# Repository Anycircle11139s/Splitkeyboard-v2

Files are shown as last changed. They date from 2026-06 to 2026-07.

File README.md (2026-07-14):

# SPLIT-KEYBOARD-V2
The second attempt of creating the prefect split keyboard by @NotALarp
## WHAT IS IT?
This is my custom split keyboard made in KiCad, based on a LILY58 split keyboard design, it is sleek and is designed with ergonomics in mind. 

## Featured Hardware:
- Nice!Nano v2 microcontroller
- Lipo batteries
- Low profile choc switches
- 0.91" OLED displays
- EC11 Rotary Encoders

## WHY I MADE IT
My first split keyboard was pretty bad, it was based on a xiao nrf58240 microcontroller, had a terrible layout and overall wasn't that good. So I decided that with my previous knowledge that I would create a new, second split keyboard. 

## NOTES AND DESIGN CHOICES
This  time I decided to base the layout on a real split keyboard and some better microcontrollers. I decided on the nice!nano v2 and based the layout on a Lily58 split keyboard which I think looks really good. I designed a custom, 3d-printed case which was created to be compact, modern and sleek. 

## GALLERY
Screenshot 2026-06-01 at 7 38 29 pm
Screenshot 2026-06-04 at 8 28 54 pm
Screenshot 2026-06-09 at 4 20 33 pm
Screenshot 2026-06-09 at 7 04 58 pm
Screenshot 2026-06-10 at 5 05 12 pm

<br>

## BOM
<br>
https://docs.google.com/document/d/1G1sLWLXkf7hAwwnX9o8N8jDjILno_Bk2AuGZwasASP0/edit?usp=sharing

<br>

<br>

|Name |Purpose |Quantity|Total Cost (USD)|Link |Distributor |
|---|---|---|---|---|---|
|M3 screws |To screw everything into place |1 |3.00 |https://www.aliexpress.com/item/1005008810897680.html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 |Ali express |
|Keycaps |to cover the switches |1 |25.00 |https://www.aliexpress.com/item/1005006734545486.html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 |Ali express |
|Case shipping and printing |The 3D printed case |1 |0.00 | |Printing Legion|
|PCB |To hold/wire everything together |1 |26.00 | |JLCPCB |
|Rubber Feat |to keep the keyboard in place while typing |1 |3.00 |https://www.aliexpress.com/item/1005009513504427.html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 |Ali express |
|Lipo batteries |For making the thing have power while wireless  |2 |14.00 |https://www.aliexpress.com/item/32660019420.html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 |Ali express |
|JST pin connector |To connect Lipo batteries |1 |1.30 |https://www.aliexpress.com/item/1005004955655144.html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 |Ali express |
|Nice!Nano 2 drop in replacement|Microcontroller |2 |12.00 |https://www.aliexpress.com/item/1005012324856273.html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 |Ali express |
|Rotary encoder |The turning sensor for volume/brightness control|2 |4.00 |https://www.aliexpress.com/item/1005006693443387.html |Ali express |
|2M resistors |Battery sensing |1 |2.30 |https://www.aliexpress.com/item/1005006984056678.html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 |Ali express |
|806K resistors |Battery Sense |1 |2.30 |https://www.aliexpress.com/item/1005005184230104.html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 |Ali express |
|OLEDs |Displays |2 |5.00 |https://www.aliexpress.com/item/1005009252203585.html |Ali express |
|Diodes |For individual keys to click |1 |2.70 |https://www.aliexpress.com/item/1005007536719404.html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 |Ali express |
|Low Profile Choc Switches |Buttons for the keyboard |1 |20.00 |https://www.aliexpress.com/item/1005005883472162.html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|Ali Express |

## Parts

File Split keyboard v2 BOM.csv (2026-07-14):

Name | Purpose | Quantity | Total Cost (USD) | Link | Distributor
M3 screws | To screw everything into place | 1 | 3.00 | https://www.aliexpress.com/item/1005008810897680.html | Ali express
Keycaps | to cover the switches | 1 | 25.00 | https://www.aliexpress.com/item/1005006734545486.html | Ali express
Case shipping and printing | The 3D printed case | 1 | 0.00 |  | Printing Legion
PCB | To hold/wire everything together | 1 | 26.00 |  | JLCPCB
Rubber Feat | to keep the keyboard in place while typing | 1 | 3.00 | https://www.aliexpress.com/item/1005009513504427.html?curPageLogUid=5WTu2EJR6cb9 | Ali express
Lipo batteries | For making the thing have power while wireless | 2 | 14.00 | https://www.aliexpress.com/item/32660019420.html | Ali express
JST pin connector | To connect Lipo batteries | 1 | 1.30 | https://www.aliexpress.com/item/1005004955655144.html?curPageLogUid=SeM6XgBLqABt | Ali express
Nice!Nano 2 drop in replacement | Microcontroller | 2 | 12.00 | https://www.aliexpress.com/item/1005012324856273.html?curPageLogUid=t0nqsjWoAD10 | Ali express
Rotary encoder | The turning sensor for volume/brightness control | 2 | 4.00 | https://www.aliexpress.com/item/1005006693443387.html | Ali express
2M resistors | Battery sensing | 1 | 2.30 | https://www.aliexpress.com/item/1005006984056678.html?curPageLogUid=W9kpVUtpsgGF | Ali express
806K resistors | Battery Sense | 1 | 2.30 | https://www.aliexpress.com/item/1005005184230104.html?curPageLogUid=3ZB85ZmHR85W | Ali express
OLEDs | Displays | 2 | 5.00 | https://www.aliexpress.com/item/1005009252203585.html | Ali express
Diodes | For individual keys to click | 1 | 2.70 | https://www.aliexpress.com/item/1005007536719404.html?curPageLogUid=7tkJWryZP639 | Ali express
Low Profile Choc Switches | Buttons for the keyboard | 1 | 20.00 | https://www.aliexpress.com/item/1005005883472162.html?curPageLogUid=ecY0FsHMIH2l | Ali Express

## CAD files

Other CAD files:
Split keyboard v2 CAD/Final Assembly/Split keyboard v2 final assembly.step
Split keyboard v2 CAD/Bottom Left/Split keyboard v2 case part 1.step
Split keyboard v2 CAD/Bottom Right/Split keyboard v2 case part 3.step
Split keyboard v2 CAD/PCB CAD/Split keyboard pcb v2.step
Split keyboard v2 CAD/Top Left/Split keyboard v2 case part 2.step
Split keyboard v2 CAD/Top Right/Split keyboard v2 case part 4.step
Split keyboard v2 CAD/Bottom Left/Split keyboard v2 case part 1.f3d
Split keyboard v2 CAD/Bottom Left/Split keyboard v2 case part 1.stl
Split keyboard v2 CAD/Bottom Right/Split keyboard v2 case part 3.f3d
Split keyboard v2 CAD/Bottom Right/Split keyboard v2 case part 3.stl
Split keyboard v2 CAD/Final Assembly/Split keyboard v2 final assembly.f3d
Split keyboard v2 CAD/Final Assembly/Split keyboard v2 final assembly.stl
Split keyboard v2 CAD/PCB CAD/Split keyboard pcb v2.stl
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

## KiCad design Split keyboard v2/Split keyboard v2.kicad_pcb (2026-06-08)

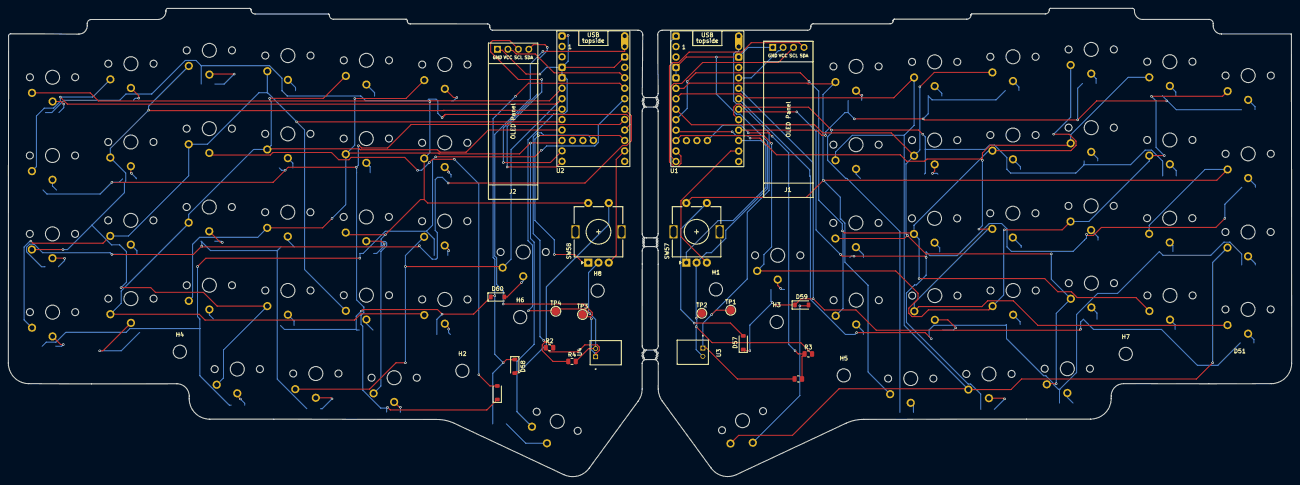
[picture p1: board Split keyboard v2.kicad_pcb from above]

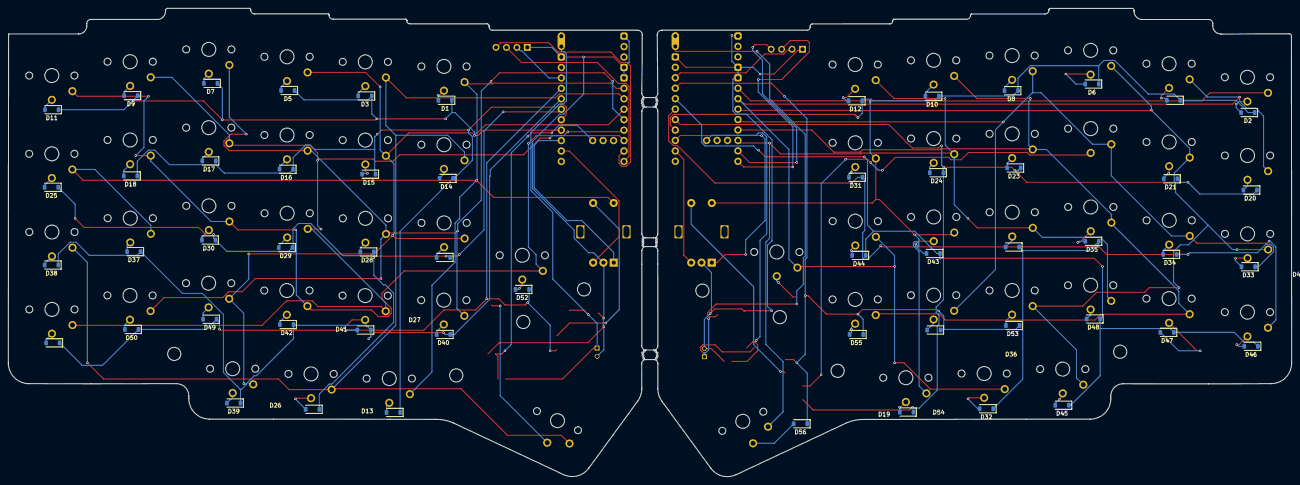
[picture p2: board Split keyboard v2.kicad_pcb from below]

Board: 2 copper layers, 312.1 x 113.9 mm, 142 parts (55 on the bottom side), 97 nets.

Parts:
CH1, CH2, CH3, CH4, CH5, CH6, CH7, CH8, CH9, CH10, CH11, CH12, CH13, CH14, CH15, CH16, CH17, CH18, CH19, CH20, CH21, CH22, CH23, CH24, CH25, CH26, CH27, CH28, CH29, CH30, CH31, CH32, CH33, CH34, CH35, CH36, CH37, CH38, CH39, CH40, CH41, CH42, CH43, CH44, CH45, CH46, CH47, CH48, CH49, CH50, CH51, CH52, CH53, CH54, CH55, CH56, CH57, CH58: choc_v1_SW_solder; SW_choc_v1_1u
D1, D2, D3, D4, D5, D6, D7, D8, D9, D10, D11, D12, D13, D14, D15, D16, D17, D18, D19, D20, D21, D22, D23, D24, D25, D26, D27, D28, D29, D30, D31, D32, D33, D34, D35, D36, D37, D38, D39, D40, D41, D42, D43, D44, D45, D46, D47, D48, D49, D50, D51, D52, D53, D54, D55, D56, D57, D58, D59, D60: D; D_SOD-123
H1, H2, H3, H4, H5, H6, H7, H8: MountingHole; MountingHole_3.2mm_M3
J1, J2: Conn_01x04_Socket; SSD1306-0.91-OLED-4pin-128x32
R1, R2: 806K; R_0805_2012Metric
R3, R4: 2M; R_0805_2012Metric
SW57, SW58: RotaryEncoder_Switch; RotaryEncoder_Alps_EC11E-Switch_Vertical_H20mm
TP1, TP3: BAT; TestPoint_Pad_D2.0mm
TP2, TP4: GND; TestPoint_Pad_D2.0mm
U1, U2: nice_nano; nice_nano_AH_USBup
U3, U4: S2B-PH-K-S(LF)(SN); JST_S2B-PH-K-S_LF__SN_

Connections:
/left/BT_PIN: R1.2, R3.1, U1.27 (P1.07-LF)
/left/COL0: CH1.1, CH13.1, CH25.1, CH37.1, SW57.S2, U1.5 (P0.17)
/left/COL1: CH3.1, CH15.1, CH27.1, CH39.1, CH57.1, U1.6 (P0.20)
/left/COL2: CH5.1, CH17.1, CH29.1, CH41.1, CH49.1, U1.7 (P0.22)
/left/COL3: CH7.1, CH19.1, CH31.1, CH43.1, CH51.1, U1.8 (P0.24)
/left/COL4: CH9.1, CH21.1, CH33.1, CH45.1, CH53.1, U1.9 (P1.00)
/left/COL5: CH11.1, CH23.1, CH35.1, CH47.1, CH55.1, U1.10 (P0.11)
/left/Encoder_A: SW57.A, U1.22 (P1.11-LF)
/left/Encoder_B: SW57.B, U1.23 (P0.10-LF)
/left/ROW0: D1.1 (K), D3.1 (K), D5.1 (K), D7.1 (K), D9.1 (K), D11.1 (K), U1.21 (P1.13-LF)
/left/ROW1: D13.1 (K), D14.1 (K), D15.1 (K), D16.1 (K), D17.1 (K), D18.1 (K), U1.20 (P1.15-LF)
/left/ROW2: D25.1 (K), D26.1 (K), D27.1 (K), D28.1 (K), D29.1 (K), D30.1 (K), U1.19 (P0.02-LF)
/left/ROW3: D37.1 (K), D38.1 (K), D39.1 (K), D40.1 (K), D41.1 (K), D42.1 (K), U1.18 (P0.29-LF)
/left/ROW4: D49.1 (K), D50.1 (K), D51.1 (K), D52.1 (K), D57.1 (K), D59.1 (K), U1.17 (P0.31-LF)
/left/SCL: J1.3, U1.12 (P1.06-LF)
/left/SDA: J1.4, U1.11 (P1.04-LF)
/left/VBAT: R1.1, TP1.1 (1_1), U1.13 (BAT+), U1.29 (BAT+), U3.1
/left/VCC: J1.2, U1.16 (3V3)
/right/BT_PIN: R2.2, R4.1, U2.27 (P1.07-LF)
/right/COL0: CH2.1, CH14.1, CH26.1, CH38.1, SW58.S2, U2.5 (P0.17)
/right/COL1: CH4.1, CH16.1, CH28.1, CH40.1, CH58.1, U2.6 (P0.20)
/right/COL2: CH6.1, CH18.1, CH30.1, CH42.1, CH50.1, U2.7 (P0.22)
/right/COL3: CH8.1, CH20.1, CH32.1, CH44.1, CH52.1, U2.8 (P0.24)
/right/COL4: CH10.1, CH22.1, CH34.1, CH46.1, CH54.1, U2.9 (P1.00)
/right/COL5: CH12.1, CH24.1, CH36.1, CH48.1, CH56.1, U2.10 (P0.11)
/right/Encoder_A: SW58.A, U2.22 (P1.11-LF)
/right/Encoder_B: SW58.B, U2.23 (P0.10-LF)
/right/ROW0: D2.1 (K), D4.1 (K), D6.1 (K), D8.1 (K), D10.1 (K), D12.1 (K), U2.21 (P1.13-LF)
/right/ROW1: D19.1 (K), D20.1 (K), D21.1 (K), D22.1 (K), D23.1 (K), D24.1 (K), U2.20 (P1.15-LF)
/right/ROW2: D31.1 (K), D32.1 (K), D33.1 (K), D34.1 (K), D35.1 (K), D36.1 (K), U2.19 (P0.02-LF)
/right/ROW3: D43.1 (K), D44.1 (K), D45.1 (K), D46.1 (K), D47.1 (K), D48.1 (K), U2.18 (P0.29-LF)
/right/ROW4: D53.1 (K), D54.1 (K), D55.1 (K), D56.1 (K), D58.1 (K), D60.1 (K), U2.17 (P0.31-LF)
/right/SCL: J2.3, U2.12 (P1.06-LF)
/right/SDA: J2.4, U2.11 (P1.04-LF)
/right/VBAT: R2.1, TP3.1 (1_1), U2.13 (BAT+), U2.29 (BAT+), U4.1
/right/VCC: J2.2, U2.16 (3V3)
GND: J1.1, J2.1, R3.2, R4.2, SW57.C, SW58.C, TP2.1 (1_1), TP4.1 (1_1), U1.3 (GND), U1.4 (GND), U1.14 (GND), U1.28 (GND), U2.3 (GND), U2.4 (GND), U2.14 (GND), U2.28 (GND), U3.2, U4.2
unnamed: CH1.2, D1.2 (A)
unnamed: CH2.2, D2.2 (A)
unnamed: CH3.2, D3.2 (A)
unnamed: CH4.2, D4.2 (A)
unnamed: CH5.2, D5.2 (A)
unnamed: CH6.2, D6.2 (A)
unnamed: CH7.2, D7.2 (A)
unnamed: CH8.2, D8.2 (A)
unnamed: CH9.2, D9.2 (A)
unnamed: CH10.2, D10.2 (A)
unnamed: CH11.2, D11.2 (A)
unnamed: CH12.2, D12.2 (A)
unnamed: CH13.2, D13.2 (A)
unnamed: CH15.2, D14.2 (A)
unnamed: CH17.2, D15.2 (A)
unnamed: CH19.2, D16.2 (A)
unnamed: CH21.2, D17.2 (A)
unnamed: CH23.2, D18.2 (A)
unnamed: CH14.2, D19.2 (A)
unnamed: CH16.2, D20.2 (A)
unnamed: CH18.2, D21.2 (A)
unnamed: CH20.2, D22.2 (A)
unnamed: CH22.2, D23.2 (A)
unnamed: CH24.2, D24.2 (A)
unnamed: CH25.2, D25.2 (A)
unnamed: CH27.2, D26.2 (A)
unnamed: CH29.2, D27.2 (A)
unnamed: CH31.2, D28.2 (A)
unnamed: CH33.2, D29.2 (A)
unnamed: CH35.2, D30.2 (A)
unnamed: CH26.2, D31.2 (A)
unnamed: CH28.2, D32.2 (A)
unnamed: CH30.2, D33.2 (A)
unnamed: CH32.2, D34.2 (A)
unnamed: CH34.2, D35.2 (A)
unnamed: CH36.2, D36.2 (A)
unnamed: CH37.2, D37.2 (A)
unnamed: CH39.2, D38.2 (A)
unnamed: CH41.2, D39.2 (A)
unnamed: CH43.2, D40.2 (A)
unnamed: CH45.2, D41.2 (A)
unnamed: CH47.2, D42.2 (A)
unnamed: CH38.2, D43.2 (A)
unnamed: CH40.2, D44.2 (A)
unnamed: CH42.2, D45.2 (A)
unnamed: CH44.2, D46.2 (A)
unnamed: CH46.2, D47.2 (A)
unnamed: CH48.2, D48.2 (A)
unnamed: CH49.2, D49.2 (A)
unnamed: CH51.2, D50.2 (A)
unnamed: CH53.2, D51.2 (A)
unnamed: CH55.2, D52.2 (A)
unnamed: CH50.2, D53.2 (A)
unnamed: CH52.2, D54.2 (A)
unnamed: CH54.2, D55.2 (A)
unnamed: CH56.2, D56.2 (A)
unnamed: D57.2 (A), SW57.S1
unnamed: D58.2 (A), SW58.S1
unnamed: CH57.2, D59.2 (A)
unnamed: CH58.2, D60.2 (A)

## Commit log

2026-06-11 Update README with CAD files link
    Added a link to Google Drive for CAD files.
2026-06-29 Add CAD folder to existing repo via LFS
    [Split keyboard pcb v2.step, Split keyboard pcb v2.stl, Split keyboard v2 case part 1.f3d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]
2026-07-14 Rename Split keyboard v2 CAD/Split keyboard v2 final assembly.f3d to Split keyboard v2 CAD/Final Assembly/Split keyboard v2 final assembly.f3d
    [Split keyboard v2 final assembly.f3d]
2026-07-14 Rename Split keyboard v2 CAD/Split keyboard v2 final assembly.stl to Split keyboard v2 CAD/Final Assembly/Split keyboard v2 final assembly.stl
    [Split keyboard v2 final assembly.stl]
2026-07-14 Rename Split keyboard v2 CAD/Split keyboard v2 final assembly.step to Split keyboard v2 CAD/Final Assembly/Split keyboard v2 final assembly.step
    [Split keyboard v2 final assembly.step]
2026-07-14 Rename Split keyboard v2 CAD/Split keyboard pcb v2.step to Split keyboard v2 CAD/PCB CAD/Split keyboard pcb v2.step
    [Split keyboard pcb v2.step]
2026-07-14 Rename Split keyboard v2 CAD/Split keyboard pcb v2.stl to Split keyboard v2 CAD/PCB CAD/Split keyboard pcb v2.stl
    [Split keyboard pcb v2.stl]
2026-07-14 Move Split keyboard v2 case part 1 to Bottom Left folder
    [Split keyboard v2 case part 1.stl]
2026-07-14 Rename Split keyboard v2 CAD/Split keyboard v2 case part 1.f3d to Split keyboard v2 CAD/Bottom Left/Split keyboard v2 case part 1.f3d
    [Split keyboard v2 case part 1.f3d]
2026-07-14 Rename Split keyboard v2 CAD/Split keyboard v2 case part 1.step to Split keyboard v2 CAD/Bottom Left/Split keyboard v2 case part 1.step
    [Split keyboard v2 case part 1.step]
2026-07-14 Rename Split keyboard v2 CAD/Split keyboard v2 case part 2.stl to Split keyboard v2 CAD/Top Left/Split keyboard v2 case part 2.stl
    [Split keyboard v2 case part 2.stl]
2026-07-14 Rename Split keyboard v2 CAD/Split keyboard v2 case part 2.f3d to Split keyboard v2 CAD/Top Left/Split keyboard v2 case part 2.f3d
    [Split keyboard v2 case part 2.f3d]
2026-07-14 Rename Split keyboard v2 CAD/Split keyboard v2 case part 2.step to Split keyboard v2 CAD/Top Left/Split keyboard v2 case part 2.step
    [Split keyboard v2 case part 2.step]
2026-07-14 Rename Split keyboard v2 CAD/Split keyboard v2 case part 3.stl to Split keyboard v2 CAD/Bottom Right/Split keyboard v2 case part 3.stl
    [Split keyboard v2 case part 3.stl]
2026-07-14 Rename Split keyboard v2 CAD/Split keyboard v2 case part 3.step to Split keyboard v2 CAD/Bottom Right/Split keyboard v2 case part 3.step
    [Split keyboard v2 case part 3.step]
2026-07-14 Rename Split keyboard v2 CAD/Split keyboard v2 case part 3.f3d to Split keyboard v2 CAD/Bottom Right/Split keyboard v2 case part 3.f3d
    [Split keyboard v2 case part 3.f3d]
2026-07-14 Rename Split keyboard v2 CAD/Split keyboard v2 case part 4.f3d to Split keyboard v2 CAD/Top Right/Split keyboard v2 case part 4.f3d
    [Split keyboard v2 case part 4.f3d]
2026-07-14 Rename Split keyboard v2 CAD/Split keyboard v2 case part 4.step to Split keyboard v2 CAD/Top Right/Split keyboard v2 case part 4.step
    [Split keyboard v2 case part 4.step]
2026-07-14 Rename Split keyboard v2 CAD/Split keyboard v2 case part 4.stl to Split keyboard v2 CAD/Top Right/Split keyboard v2 case part 4.stl
    [Split keyboard v2 case part 4.stl]
